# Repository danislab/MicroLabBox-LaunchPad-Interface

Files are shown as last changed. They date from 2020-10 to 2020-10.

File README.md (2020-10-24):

# dSPACE MicroLabBox TI LaunchPad Interface PCB

The MicroLabBox LaunchPad Interface is a simple PCB to connect LaunchPads from Texas Instruments (TI) to the MicroLabBox from dSPACE to perform real-time Hardware-in-the-Loop (HIL) tests. This Interface PCB can be used to accelerate the development and validation of software and algorithms running on MCUs from TI.
Depending on the LaunchPad the interface PCB offers up to 28 digital IOs, 16 analog inputs (LaunchPad side), 4 analog outputs (LaunchPad side) and two independent CAN interfaces.

Picture of dSPACE MicroLabBox TI LaunchPad Interface PCB dSPACE MicroLabBox TI LaunchPad Interface PCB

## Status
* The Interface PCB was tested with LaunchPads for the TI MCUs F28377S, 570LS12x and 570LC43x.
* The position of the CAN connector for the dSPACE MicroLabBox is not correct aligned with the connectors of the connector group B. As workaround, a straight D-sub connector can be connected with wires to the PCB. In a future release this problem will be solved with a connector that is in line with the other two 50 pol connectors of the connector group B.

## Connectors
* J1 - J4 are used to connect the LaunchPad to the Interface PCB. The labelling and pin assignment follows the TIBoosterPack standard from Texas Instruments.
* J5 is used to connect the Interface PCB to the digital IOs from the dSPACE MicroLabBox. The connector is made of machined contacts which minimises wear and tear of the MicroLabBox connectors.
* J6 is used to connect the Interface PCB to the analogue IOs from the dSPACE MicroLabBox. The connector is made of machined contacts which minimises wear and tear of the MicroLabBox connectors.
* J7 is used to connect the Interface PCB to the two CAN interface of the dSPACE MicroLabBox. The connector is made of machined contacts which minimises wear and tear of the MicroLabBox connectors.
* J8 - J9 are used to connect a external CAN interface over a 9 pin D-sub. E.g. Vector, PEAK, Kvaser...
* J10 and J13 are used for the CAN Rx and Tx pins of the MCU.
* J11 and J14 are used for CAN high and CAN low for the CAN transceiver in case one is already soldered to the LanchPad.
* J12 and J15 are used to enable the 120Ohm terminator resistor for the CAN interface.

## Pinout
The pinout of the CAN interface follows the ISO 11898 specification
* Pin 2 is for CAN low
* Pin 7 is for CAN high

The pinout of the connectors J1 - J4 is described in the following table.

| TIBoosterPack standard | | F28377S  | F28379D  | TMS 570LS12x and TMS 570LC43x  | dSPace MicroLabBox | | |
|---|-----|---|---|---|---|-----|---|
| Connector | Pin | Function | Function | Function | Connector | Pin | Function |
| J1 | 1 | +3.3 V | +3.3V | +3.3 V | | | |
| J1 | 2 | GPIO71 | GPIO32 | AD1IN[16] | | | |
| J1 | 3 | GPIO90 | GPIO19 | SCIRX | | | |
| J1 | 4 | GPIO89 | GPIO18 | SCITX | | | |
| J1 | 5 | GPIO41 | GPIO67 | GIOA[7] | Digital I/O B | 33  | DIO2ch1  |
| J1 | 6 | NC | GPIO111  | AD1IN[17] | | | |
| J1 | 7 | GPIO60 | GPIO60 | MIBSPI3CLK | | | |
| J1 | 8 | GPIO61 | GPIO22 | GIOA[6] | Digital I/O B | 32  | DIO2ch2  |
| J1 | 9 | GPIO43 | GPIO105  | N2HET1[4] | Digital I/O B | 31  | DIO2ch3  |
| J1 | 10  | GPIO42 | GPIO104  | N2HET1[9] | Digital I/O B | 29  | DIO2ch4  |
| | | | | | | | |
| J2 | 20  | GND | GND | GND | | | |
| J2 | 19  | GPIO4 | GPIO61 | N2HET1[22] | | | |
| J2 | 18  | GPIO62 | GPIO123  | MIBSPI3NCS[1] | | | |
| J2 | 17  | NC | GPIO122  | GIOB[3] | | | |
| J2 | 16  | RESET | RESET | RESET | | | |
| J2 | 15  | GPIO58 | GPIO58 | MIBSPI3SIMO | | | |
| J2 | 14  | GPIO59 | GPIO59 | MIBSPI3SOMI | | | |
| J2 | 13  | GPIO72 | GPIO124  | N2HET1[27] | Digital I/O B | 28  | DIO2ch5  |
| J2 | 12  | GPIO73 | GPIO125  | N2HET1[29] | Digital I/O B | 27  | DIO2ch6  |
| J2 | 11  | GPIO78 | GPIO29 | GIOB[2] | Digital I/O B | 25  | DIO2ch7  |
| | | | | | | | |
| J3 | 21  | +5 V | +5 V | +5 V | | | |
| J3 | 22  | GND | GND | GND | | | |
| J3 | 23  | ADCIN14  | ADCIN14  | AD1[0] | Analog I/O B | 49  | AO1ch1 |
| J3 | 24  | ADCINB1  | ADCINC3  | AD1[7] | Analog I/O B | 32  | AO1ch2 |
| J3 | 25  | ADCINB4  | ADCINB3  | AD1IN[18] | Analog I/O B | 47  | AO1ch3 |
| J3 | 26  | ADCINB2  | ADCINA3  | AD1IN[19] | Analog I/O B | 30  | AO1ch4 |
| J3 | 27  | ADCINA0  | ADCINC2  | AD1IN[20] | Analog I/O B | 45  | AO1ch5 |
| J3 | 28  | ADCINB0  | ADCINB2  | AD1IN[21] | Analog I/O B | 28  | AO1ch6 |
| J3 | 29  | ADCINA1  | ADCINA2  | | Analog I/O B | 43  | AO1ch7 |
| J3 | 30  | NC | ADCINA0  | | Analog I/O B | 26  | AO1ch8 |
| | | | | | | | |
| J4 | 40  | GPIO12 | GPIO0 | N2HET1[20] | Digital I/O B | 17  | DIO1ch33 |
| J4 | 39  | GPIO13 | GPIO1 | N2HET1[18] | Digital I/O B | 16  | DIO1ch34 |
| J4 | 38  | GPIO14 | GPIO2 | N2HET1[16] | Digital I/O B | 15  | DIO1ch35 |
| J4 | 37  | GPIO15 | GPIO3 | N2HET1[30] | Digital I/O B | 14  | DIO1ch36 |
| J4 | 36  | GPIO16 | GPIO4 | N2HET1[14] | Digital I/O B | 13  | DIO1ch37 |
| J4 | 35  | GPIO17 | GPIO5 | N2HET1[12] | Digital I/O B | 12  | DIO1ch38 |
| J4 | 34  | GPIO20 | GPIO24 | GIOA[5] | Digital I/O B | 11  | DIO1ch39 |
| J4 | 33  | GPIO21 | GPIO16 | GIOA[2] | Digital I/O B | 10  | DIO1ch40 |
| J4 | 32  | DAC1 | DAC1 | GIOA[1] | Analog I/O B | 17  | AI2ch1 |
| J4 | 31  | DAC2 | DAC2 | GIOA[0] | Analog I/O B | 15  | AI2ch2 |
| | | | | | | | |
| J6 | 41  | +3.3 V | +3.3 V | +3.3 V | | | |
| J6 | 42  | NC | GPIO95 | AD1IN[9] | | | |
| J6 | 43  | GPIO87 | GPIO139  | LIN1_RXD | | | |
| J6 | 44  | GPIO86 | GPIO56 | LIN1_TXD | | | |
| J6 | 45  | NC | GPIO97 | GIOB[2] | | | |
| J6 | 46  | NC | GPIO94 | AD1IN[1] | | | |
| J6 | 47  | GPIO65 | GPIO65 | MIBSPI1CLK | Digital I/O B | 24  | DIO2ch8  |
| J6 | 48  | NC | GPIO52 | N2HET1[31] | Digital I/O B | 23  | DIO2ch9  |
| J6 | 49  | GPIO69 | GPIO41 | N2HET1[24] | | | |
| J6 | 50  | GPIO66 | GPIO40 | N2HET1[26] | | | |
| | | | | | | | |
| J7 | 60  | GND | GND | GND | | | |
| J7 | 59  | GPIO91 | GPIO66 | N2HET2[8] | | | |
| J7 | 58  | NC | GPIO131  | MIBSPI1SOMI[1] | | | |
| J7 | 57  | NC | GPIO130  | MIBSPI5SIMO[0] | | | |
| J7 | 56  | RESET | RESET | RESET | | | |
| J7 | 55  | GPIO63 | GPIO63 | MIBSPI1SIMO | | | |
| J7 | 54  | GPIO64 | GPIO64 | MIBSPI1SOMI | | | |
| J7 | 53  | GPIO99 | GPIO26 | N2HET1[17] | Digital I/O B | 21  | DIO2ch10 |
| J7 | 52  | GPIO92 | GPIO27 | N2HET1[19] | Digital I/O B | 20  | DIO2ch11 |
| J7 | 51  | NC | GPIO25 | MIBSPI5SOMI[0] | Digital I/O B | 19  | DIO2ch12 |
| | | | | | | | |
| J8 | 61  | +5 V | +5 V | +5 V | | | |
| J8 | 62  | GND | GND | GND | | | |
| J8 | 63  | ADCIN15  | ADCIN15  | AD1IN[10] | Analog I/O B | 41  | AO1ch9 |
| J8 | 64  | ADCINA2  | ADCINC5  | AD1IN[2] | Analog I/O B | 24  | AO1ch10  |
| J8 | 65  | ADCINA5  | ADCINB5  | AD1IN[3] | Analog I/O B | 39  | AO1ch11  |
| J8 | 66  | ADCINB5  | ADCINA5  | AD1IN[11] | Analog I/O B | 22  | AO1ch12  |
| J8 | 67  | ADCINA3  | ADCINC4  | AD1IN[4] | Analog I/O B | 37  | AO1ch13  |
| J8 | 68  | ADCINB3  | ADCINB4  | AD1IN[12] | Analog I/O B | 20  | AO1ch14  |
| J8 | 69  | ADCINA4  | ADCINA4  | NC | Analog I/O B | 35  | AO1ch15  |
| J8 | 70  | NC | ADCINA1  | NC | Analog I/O B | 18  | AO1ch16  |
| | | | | | | | |
| J9 | 80  | GPIO2 | GPIO6 | N2HET1[10] | Digital I/O B | 9 | DIO1ch41 |
| J9 | 79  | GPIO3 | GPIO7 | N2HET1[28] | Digital I/O B | 8 | DIO1ch42 |
| J9 | 78  | GPIO10 | GPIO8 | N2HET1[8] | Digital I/O B | 7 | DIO1ch43 |
| J9 | 77  | GPIO11 | GPIO9 | N2HET1[23] | Digital I/O B | 6 | DIO1ch44 |
| J9 | 76  | GPIO18 | GPIO10 | MIBSPI5NENA | Digital I/O B | 5 | DIO1ch45 |
| J9 | 75  | GPIO19 | GPIO11 | N2HET2[18] | Digital I/O B | 4 | DIO1ch46 |
| J9 | 74  | NC | GPIO14 | GIOB[1] | Digital I/O B | 3 | DIO1ch47 |
| J9 | 73  | NC | GPIO15 | GIOB[0] | Digital I/O B | 2 | DIO1ch48 |
| J9 | 72  | DAC3 | DAC3 | AD1EVT | Analog I/O B | 13  | AI2ch3 |
| J9 | 71  | DAC4 | DAC4 | MIBSPI5CLK | Analog I/O B | 11  | AI2ch4 |

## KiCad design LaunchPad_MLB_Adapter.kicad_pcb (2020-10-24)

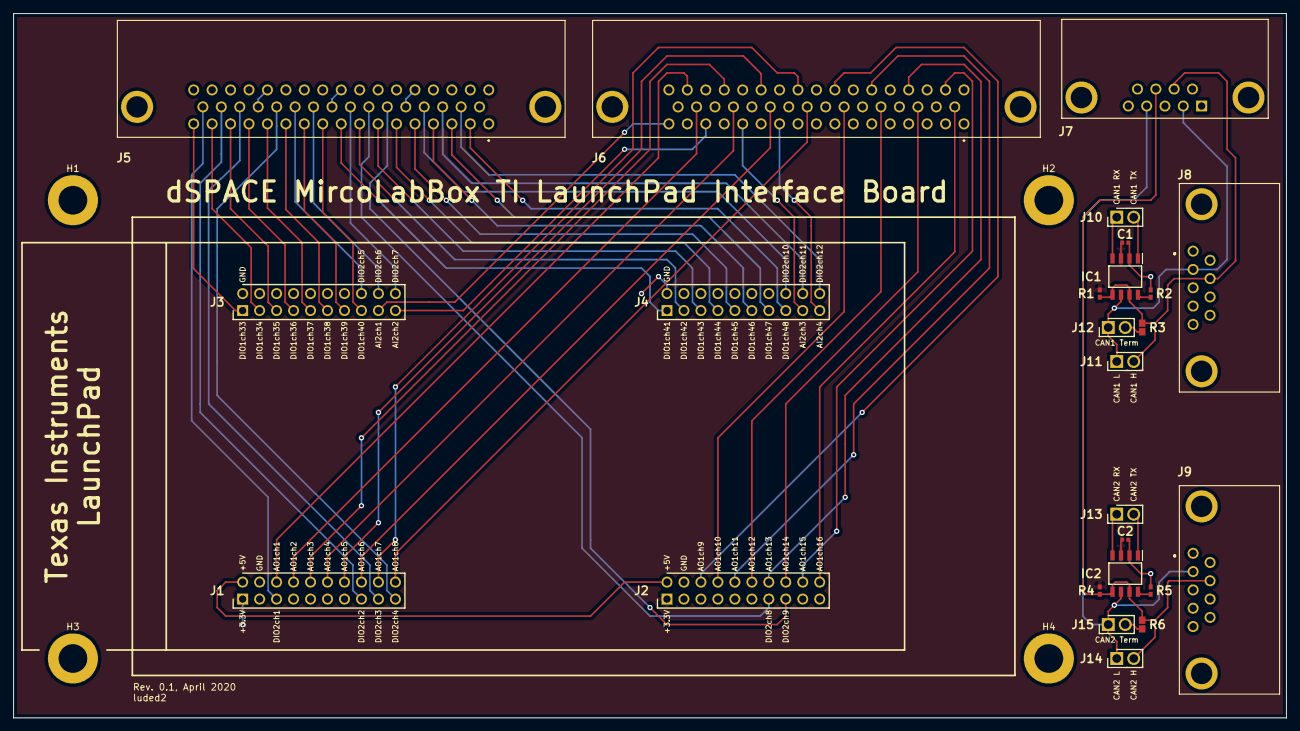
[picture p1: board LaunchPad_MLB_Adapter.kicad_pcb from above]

Board: 2 copper layers, 190.5 x 105.4 mm, 29 parts (0 on the bottom side), 63 nets.

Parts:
C1, C2: GRM155R61A104KA01D; CAPC1005X55N
H1, H2, H3, H4: MountingHole_Pad; MountingHole_4.3mm_M4_DIN965_Pad
IC1, IC2: SN65HVD234DR; SOIC127P600X175-8N
J1, J2, J3, J4: 61302021121; HDRV20W64P254X254_2X10_2540X508X869P
J5, J6: 09665627812
J7: 09661626812
J8, J9: 09661526613
J10, J11, J12, J13, J14, J15: 61300211121; HDRV2W110P0X254_1X2_508X254X854P
R1, R2, R4, R5: RC0402FR-0710KL; RESC1005X40N
R3, R6: RC0603FR-07120RL; RESC1608X55N

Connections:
+3V3: C1.1, C2.1, IC1.3, IC2.3, J1.1, J2.1, R1.1, R4.1
+5V: J1.2, J2.2
/AI2ch1: J3.17, J6.17
/AI2ch2: J3.19, J6.15
/AI2ch3: J4.17, J6.13
/AI2ch4: J4.19, J6.11
/AO1ch1: J1.6, J6.49
/AO1ch2: J1.8, J6.32
/AO1ch3: J1.10, J6.47
/AO1ch4: J1.12, J6.30
/AO1ch5: J1.14, J6.45
/AO1ch6: J1.16, J6.28
/AO1ch7: J1.18, J6.43
/AO1ch8: J1.20, J6.26
/AO1ch9: J2.6, J6.41
/AO1ch10: J2.8, J6.24
/AO1ch11: J2.10, J6.39
/AO1ch12: J2.12, J6.22
/AO1ch13: J2.14, J6.37
/AO1ch14: J2.16, J6.20
/AO1ch15: J2.18, J6.35
/AO1ch16: J2.20, J6.18
/CANHch1: IC1.5, IC1.7, J7.7, J8.7, J11.2, R1.2, R3.2
/CANHch2: IC2.5, IC2.7, J7.8, J9.7, J14.2, R4.2, R6.2
/CANLch1: IC1.6, J7.2, J8.2, J11.1, J12.1
/CANLch2: IC2.6, J7.4, J9.2, J14.1, J15.1
/DIO1ch33: J3.1, J5.17
/DIO1ch34: J3.3, J5.16
/DIO1ch35: J3.5, J5.15
/DIO1ch36: J3.7, J5.14
/DIO1ch37: J3.9, J5.13
/DIO1ch38: J3.11, J5.12
/DIO1ch39: J3.13, J5.11
/DIO1ch40: J3.15, J5.10
/DIO1ch41: J4.1, J5.9
/DIO1ch42: J4.3, J5.8
/DIO1ch43: J4.5, J5.7
/DIO1ch44: J4.7, J5.6
/DIO1ch45: J4.9, J5.5
/DIO1ch46: J4.11, J5.4
/DIO1ch47: J4.13, J5.3
/DIO1ch48: J4.15, J5.2
/DIO2ch1: J1.5, J5.33
/DIO2ch2: J1.15, J5.32
/DIO2ch3: J1.17, J5.31
/DIO2ch4: J1.19, J5.29
/DIO2ch5: J3.16, J5.28
/DIO2ch6: J3.18, J5.27
/DIO2ch7: J3.20, J5.25
/DIO2ch8: J2.13, J5.24
/DIO2ch9: J2.15, J5.23
/DIO2ch10: J4.16, J5.21
/DIO2ch11: J4.18, J5.20
/DIO2ch12: J4.20, J5.19
GND: C1.2, C2.2, IC1.2, IC2.2, J1.4, J2.4, J3.2, J4.2, J5.1, J5.18, J5.22, J5.26, J5.30, J5.34, J5.38, J5.42, J5.46, J5.50, J5.MH1, J5.MH2, J6.1, J6.2, J6.4, J6.6, J6.8, J6.10, J6.12, J6.14, J6.16, J6.34, J6.36, J6.38, J6.40, J6.42, J6.44, J6.46, J6.48, J6.50, J6.MH1, J6.MH2, J7.3, J7.MH1, J7.MH2, J8.MH1, J8.MH2, J9.MH1, J9.MH2, R2.2, R5.2
unnamed: IC1.1, J10.2
unnamed: IC1.4, J10.1
unnamed: IC1.8, R2.1
unnamed: IC2.1, J13.2
unnamed: IC2.4, J13.1
unnamed: IC2.8, R5.1
unnamed: J12.2, R3.1
unnamed: J15.2, R6.1

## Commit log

2020-10-23 added KiCad projetct files and customer library
    [LaunchPad_MLB_Adapter.kicad_pcb, LaunchPad_MLB_Adapter.sch]
2020-10-24 Added image of PCB for Readme
